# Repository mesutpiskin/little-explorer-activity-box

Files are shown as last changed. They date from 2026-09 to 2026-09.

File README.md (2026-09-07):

# Little Explorer Activity Box

[English](README.md) | [Türkçe](README.tr.md)

A no-code, no-PCB activity box that teaches cause and effect through lights,
switches, a dimmer, and sound. The enclosure is parametric, printable on a
standard 3D printer, and closed with serviceable snap fits instead of screws.

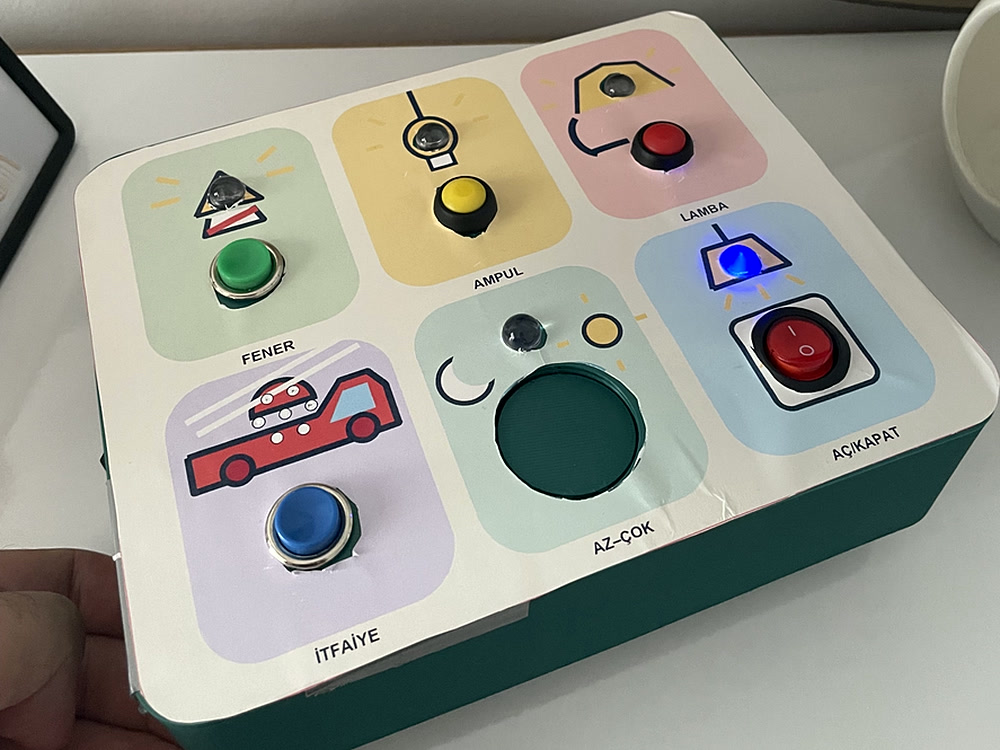
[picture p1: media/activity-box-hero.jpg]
Completed real-world activity box


> [!WARNING]
> This community hardware project is not a certified toy. A child aged 18
> months must use it only under direct adult supervision. Pull-test every
> exposed component and the back plate before each use. Remove the batteries
> immediately if anything cracks, loosens, leaks, or becomes warm.

## See it in action

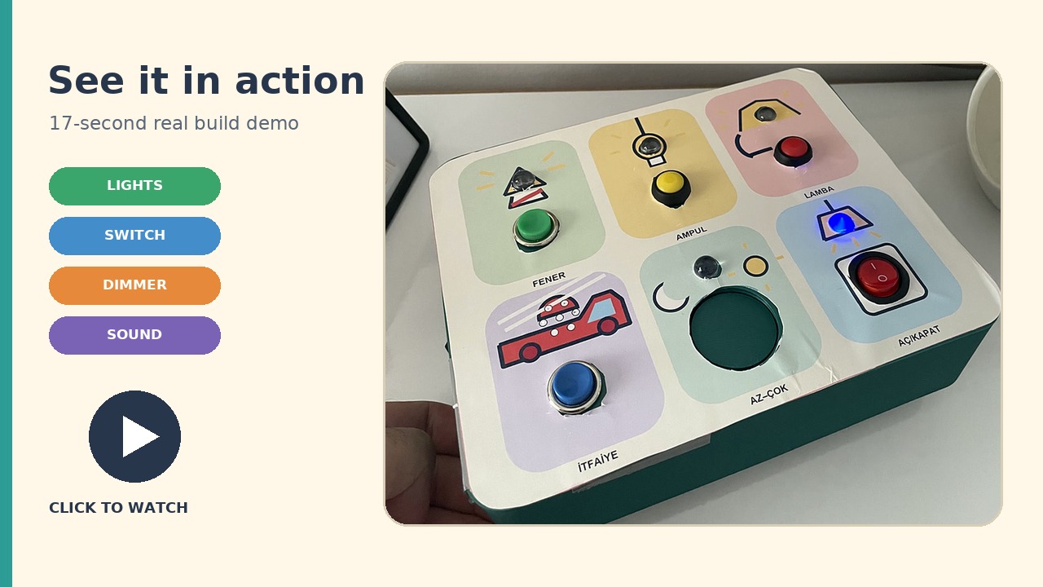
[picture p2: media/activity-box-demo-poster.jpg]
Watch the Little Explorer Activity Box demo


▶ **[Watch the 17-second real-build demo](media/activity-box-demo.mp4).** It
shows the push-button lights, maintained on/off switch, dimmer, and sound
control working on the completed box.

## What children can explore

| Activity | Input | Result |
|---|---|---|
| Lamp | Red DC184 button | Red LED lights |
| Bulb | Yellow DC184 button | Yellow LED lights |
| Beacon | Black DC180 button | Green LED lights |
| On/off | DC131A switch | Blue LED stays on or off |
| Dimmer | 1K potentiometer dial | White LED changes brightness |
| Fire engine | Blue DC180 button | Active buzzer sounds |

The six functions are simple parallel branches. No microcontroller,
breadboard, firmware, or custom PCB is required.

## Build order

### 1. Prepare the parts

Core hardware:

| Qty | Part | Purpose |
|---:|---|---|
| 2 | Semi-enclosed 2×AA battery holder | Four AA cells in series |
| 4 | AA alkaline cell | Nominal 6 V supply |
| 2 | DC184 momentary button, red and yellow | Red/yellow LED branches |
| 2 | DC180 momentary button, black and blue | Green LED and buzzer |
| 1 | DC131A 20 mm on/off switch | Blue LED branch |
| 1 | DC120 2P on/off switch | Main power |
| 1 | 1K potentiometer | White LED dimmer |
| 5 | 10 mm LED: red, yellow, green, blue, white | Light outputs |
| 5 | 330 Ω / 1 W resistor | One per LED |
| 1 | 12 mm active buzzer, 5–12 V | Sound output |
| 1 | 1 A fuse with enclosed holder | Battery short-circuit protection |
| — | Stranded wire, heat-shrink, neutral-cure silicone | Safe assembly |
| — | PETG filament | Body, back plate, and dial |

See the printable [bill of materials](docs/BOM.csv) for exact specifications.

### 2. Print the test parts first

Generate the models with:

```sh
make stl
```

Print these before the full enclosure:

- `output/stl/component-fit-test.stl` checks the purchased component sizes.
- `output/stl/snap-fit-test.stl` checks the screwless back-plate clips.

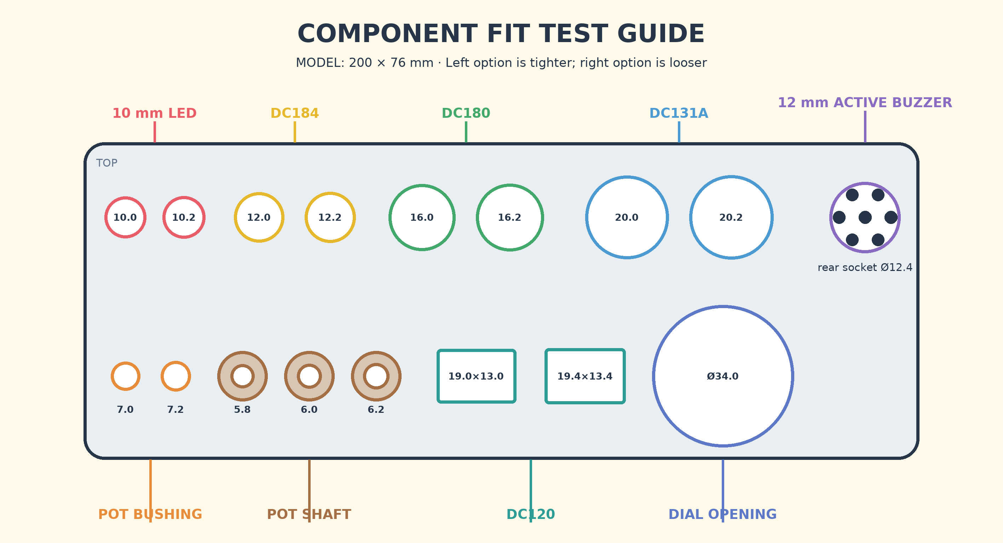
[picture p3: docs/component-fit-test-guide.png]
Component fit-test guide


The selected defaults are LED Ø10.2 mm, DC184 Ø12.0 mm, DC180 Ø16.0 mm,
DC131A Ø20.2 mm, DC120 19.0×13.0 mm, pot bushing/shaft Ø7.0/Ø6.2 mm,
and a Ø34 mm dial opening. If another fit works better, update
[`tools/project_spec.py`](tools/project_spec.py) and run `make dimensions`.

### 3. Print the enclosure

`make stl` produces:

- `activity-box-body.stl`
- `activity-box-back.stl`
- `activity-box-dial.stl`
- `snap-fit-test.stl`
- `component-fit-test.stl`

Recommended settings: PETG, 0.20 mm layers, at least four walls, five top and
bottom layers, and 25% infill. The captive dial uses a Ø36 mm × 4 mm flange
inside a Ø34 mm panel opening.

### 4. Print and apply the label

Print [the A4 label](artwork/activity-box-label-a4.pdf) at **actual size / 100%**
with “fit to page” and mirror/transfer printing disabled. The control square
must measure exactly 20 mm. Apply the label before installing components.

Editable vector source: [activity-box-label.svg](artwork/activity-box-label.svg).

### 5. Install the components

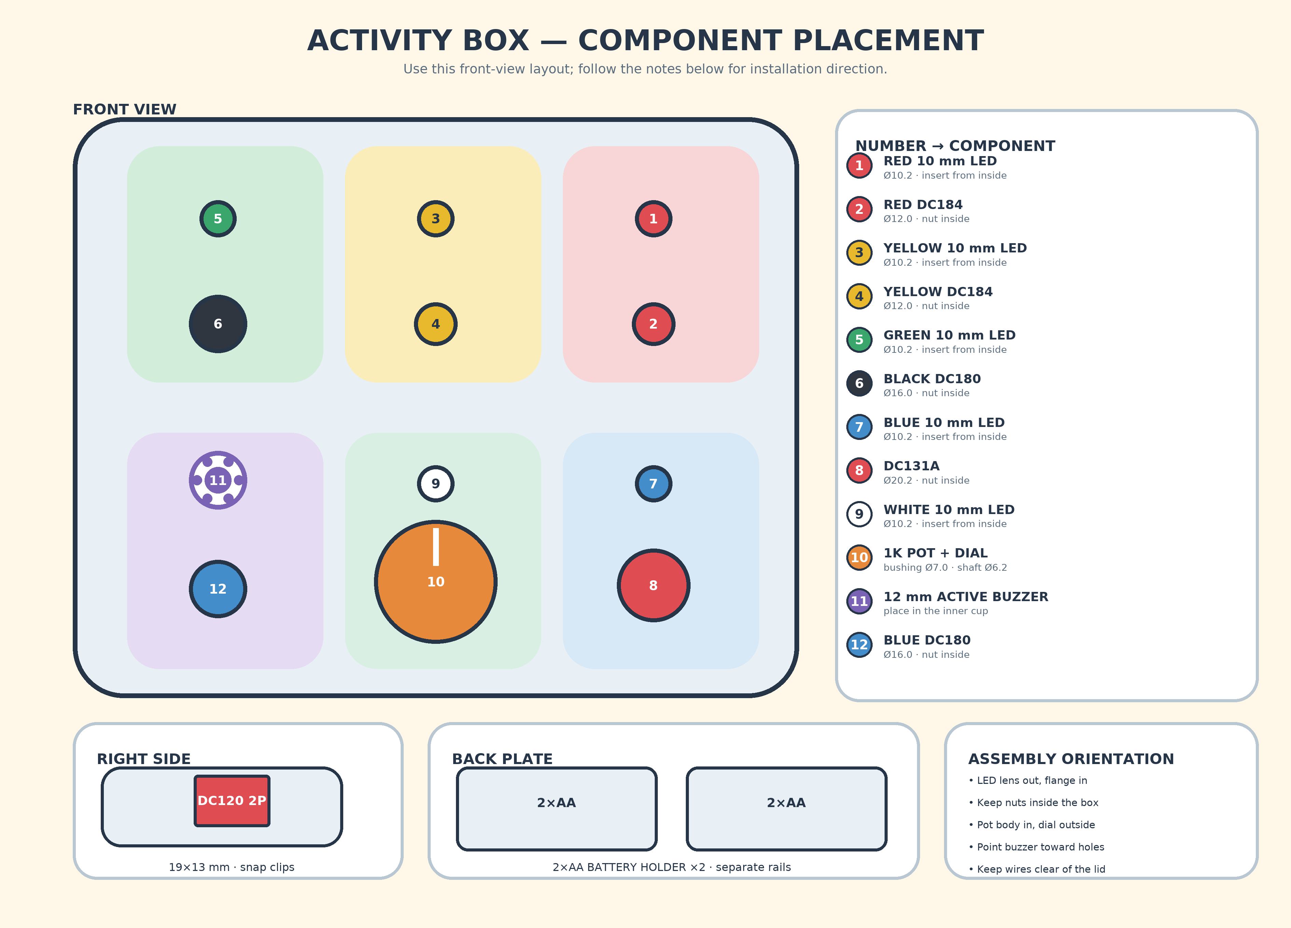
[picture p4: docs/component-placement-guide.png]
Component placement guide


Insert LEDs from inside so their wider flange remains captive. Use component
nuts or built-in clips as the primary retainers. Neutral-cure silicone may
support LEDs against vibration but must not be the only mechanical retention.
Keep the buzzer sound holes open.

The complete procedure is in the [assembly guide](docs/assembly.md).

### 6. Wire the circuit

Wiring diagram

Build the supply first, with all batteries removed:

```text
Holder A black ───────────────────────────────────── negative bus
Holder A red ─── Holder B black
Holder B red ─── 1 A fuse ─── DC120 main switch ─── positive bus
```

Then add the six branches in parallel:

```text
Positive → red DC184    → 330 Ω → red LED    → negative
Positive → yellow DC184 → 330 Ω → yellow LED → negative
Positive → black DC180  → 330 Ω → green LED  → negative
Positive → DC131A       → 330 Ω → blue LED   → negative
Positive → 1K pot       → 330 Ω → white LED  → negative
Positive → blue DC180           → active buzzer → negative
```

Use only the two switching contacts on the DC131A; leave its 12 V lamp terminal
disconnected. Identify the contacts with a multimeter instead of assuming pin
order. Join the pot wiper to the outer terminal being used.

### 7. Verify and close

1. With batteries removed, verify there is no short between the buses.
2. Confirm battery current is zero with the DC120 switched off.
3. Test one branch at a time; each LED must stay below 20 mA.
4. Route every insulated wire away from the snap clips.
5. Engage all four back-plate clips.
6. Pull-test every exposed part and the back plate before each use.

## Repository layout

| Path | Contents |
|---|---|
| [`cad/`](cad/activity_box.scad) | Parametric OpenSCAD source |
| [`artwork/`](artwork/activity-box-label.svg) | English printable label and previews |
| [`artwork/tr/`](artwork/tr/activity-box-label.svg) | Turkish printable label and previews |
| [`docs/`](docs/assembly.md) | English assembly, BOM, circuit, and placement guides |
| [`docs/tr/`](docs/tr/assembly.md) | Turkish documentation set |
| [`media/`](media/activity-box-hero.jpg) | Real-build photo, video, and video poster |
| [`assets/fonts/`](assets/fonts/LICENSE.txt) | Bundled font and its upstream license for reproducible graphics |
| [`tools/`](tools/project_spec.py) | Shared dimensions and deterministic generators |
| [`tests/`](tests/test_project_spec.py) | Geometry, output, and documentation checks |

## Rebuild and verify

Python 3 and Pillow generate the documents and artwork. OpenSCAD is required
only for STL export.

```sh
python3 -m pip install -r requirements.txt
make dimensions artwork docs
make test
make stl
make validate
```

See [CONTRIBUTING.md](CONTRIBUTING.md) before proposing changes.

## License

Hardware design, CAD, artwork, and documentation are licensed under
[CERN-OHL-P-2.0](LICENSE). Build scripts and tests are licensed under the
[MIT License](LICENSES/MIT.txt). See [license scope](LICENSES/README.md).

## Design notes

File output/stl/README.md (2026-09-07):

# STL export

[English](README.md) | [Türkçe](README.tr.md)

Generated STL files are intentionally not committed. Install OpenSCAD, then
run the following commands from the repository root:

```sh
make stl
make validate
```

The export creates:

- `activity-box-body.stl`
- `activity-box-back.stl`
- `activity-box-dial.stl`
- `snap-fit-test.stl`
- `component-fit-test.stl`

Print and verify the two test models before printing the enclosure.

## Print orientation

- Body: print with the front face down on the build plate.
- Back plate: print with the outer face down on the build plate.
- Dial: print with the flange down on the build plate.

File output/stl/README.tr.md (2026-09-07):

# STL dışa aktarma

[English](README.md) | [Türkçe](README.tr.md)

Üretilmiş STL dosyaları repoya eklenmez. OpenSCAD'i kurduktan sonra proje
kökünde şu komutları çalıştırın:

```sh
make stl
make validate
```

Oluşturulan dosyalar:

- `activity-box-body.stl`
- `activity-box-back.stl`
- `activity-box-dial.stl`
- `snap-fit-test.stl`
- `component-fit-test.stl`

Ana kutudan önce iki test modelini basıp doğrulayın.

## Baskı yönü

- Gövde: ön yüzü tablaya gelecek şekilde basın.
- Arka kapak: dış yüzü tablaya gelecek şekilde basın.
- Çark: flanşı tablaya gelecek şekilde basın.

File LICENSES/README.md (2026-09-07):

# License scope

[English](README.md) | [Türkçe](README.tr.md)

This repository uses two permissive licenses so that hardware design files and
software tooling receive terms appropriate to their use.

## CERN-OHL-P-2.0

The [CERN Open Hardware Licence Version 2 — Permissive](../LICENSE) applies to:

- `cad/`
- `artwork/`
- `docs/`
- `media/`
- `output/`
- `assets/`, except the third-party `assets/fonts/` directory covered below
- `README.md` and `README.tr.md`
- `CONTRIBUTING.md` and `CONTRIBUTING.tr.md`

SPDX identifier: `CERN-OHL-P-2.0`

## MIT

The [MIT License](MIT.txt) applies to:

- `tools/`
- `tests/`
- `Makefile`
- automation and configuration files

SPDX identifier: `MIT`

## Third-party fonts

The DejaVu Sans font files in `assets/fonts/` retain their upstream license.
See [`assets/fonts/LICENSE.txt`](../assets/fonts/LICENSE.txt).

Unless a file states otherwise, contributions are accepted under the license
assigned to that path above.

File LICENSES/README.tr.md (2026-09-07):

# Lisans kapsamı

[English](README.md) | [Türkçe](README.tr.md)

Bu repo, donanım tasarım dosyaları ile yazılım araçlarının kullanımına uygun
koşullar sağlamak için iki izin verici lisans kullanır.

## CERN-OHL-P-2.0

[CERN Açık Donanım Lisansı Sürüm 2 — Permissive](../LICENSE) şu yollar için
geçerlidir:

- `cad/`
- `artwork/`
- `docs/`
- `media/`
- `output/`
- Aşağıda belirtilen üçüncü taraf `assets/fonts/` dizini hariç `assets/`
- `README.md` ve `README.tr.md`
- `CONTRIBUTING.md` ve `CONTRIBUTING.tr.md`

SPDX kimliği: `CERN-OHL-P-2.0`

## MIT

[MIT Lisansı](MIT.txt) şu yollar için geçerlidir:

- `tools/`
- `tests/`
- `Makefile`
- otomasyon ve yapılandırma dosyaları

SPDX kimliği: `MIT`

## Üçüncü taraf fontlar

`assets/fonts/` altındaki DejaVu Sans dosyaları kendi kaynak lisanslarını
korur. Bkz. [`assets/fonts/LICENSE.txt`](../assets/fonts/LICENSE.txt).

Bir dosyada aksi belirtilmedikçe katkılar yukarıda o dosya yoluna atanan
lisans altında kabul edilir.

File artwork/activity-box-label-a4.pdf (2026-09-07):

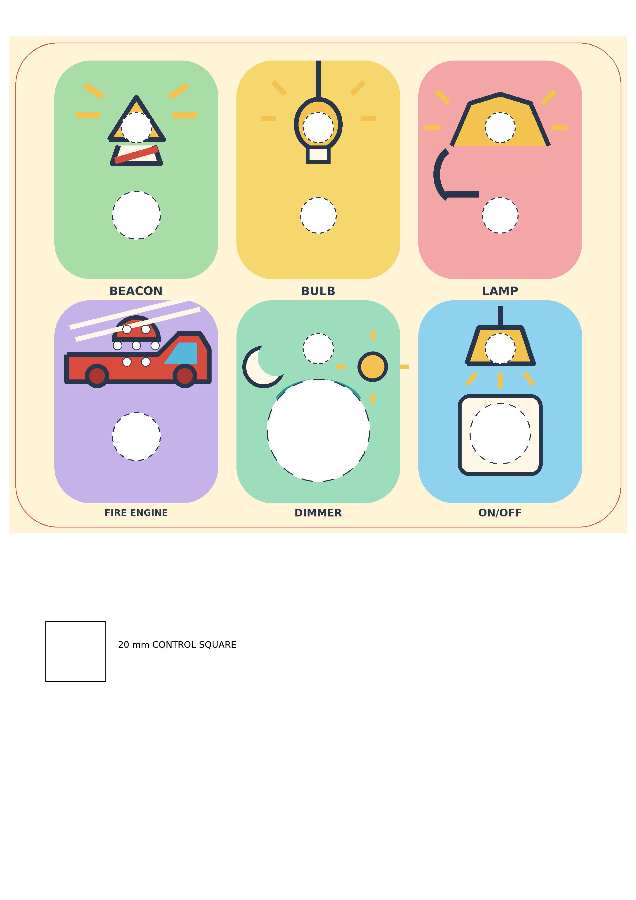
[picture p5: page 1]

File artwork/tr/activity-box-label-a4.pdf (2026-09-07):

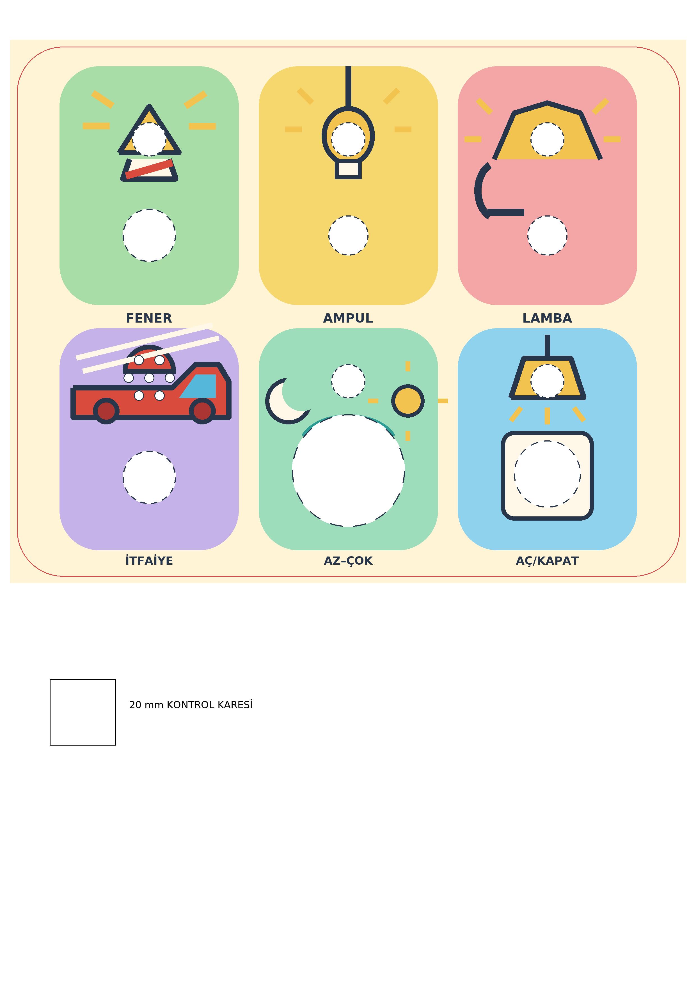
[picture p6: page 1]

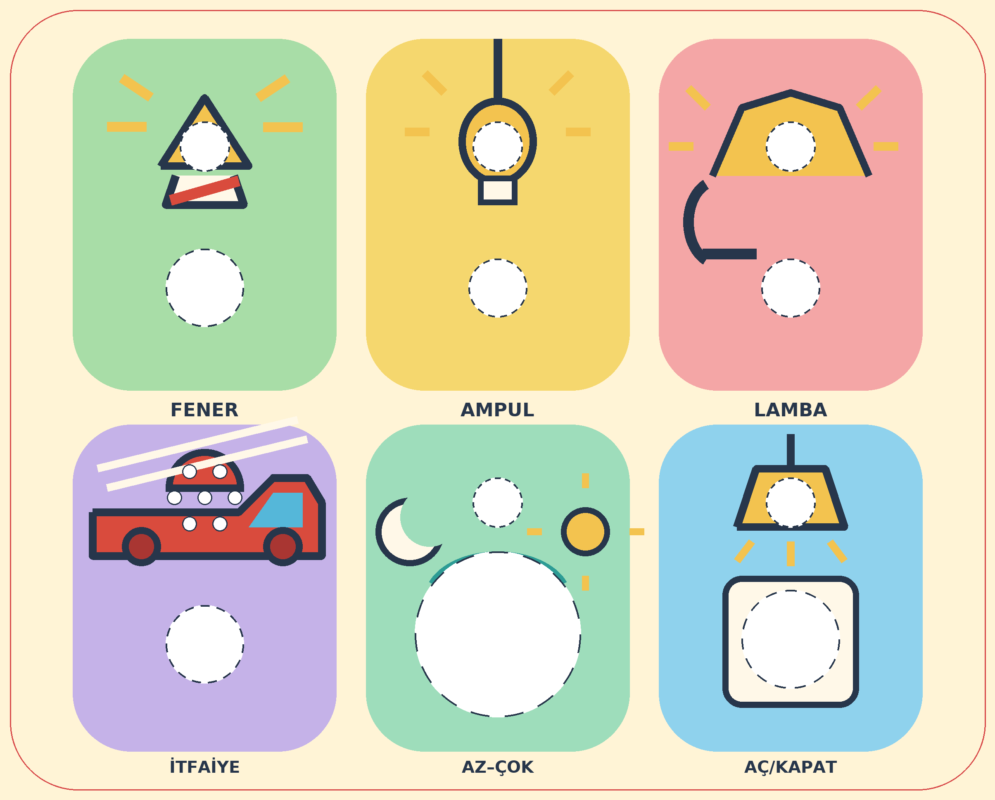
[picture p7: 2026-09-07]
artwork/tr/activity-box-label-preview.png

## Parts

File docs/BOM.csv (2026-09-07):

quantity | part | specification | use
1 | 1 A fuse | Enclosed holder or inline type | As close as possible to Holder B positive
2 | 2×AA semi-enclosed battery holder | Approx. 58×32×15 mm | Series connection for 4×AA
4 | AA alkaline battery | 1.5 V; matching brand and state of charge | 6 V nominal supply
2 | DC184 momentary push button | Red and yellow; Ø12.0 mm tested hole | Red and yellow LED branches
2 | DC180 momentary push button | Black and blue; Ø16.0 mm tested hole | Green LED and buzzer
1 | DC131A on/off switch | Ø20.2 mm; 12 V illuminated type | Use switch contacts only
1 | DC120 2P on/off switch | 19.0×13.0 mm tested cutout | Main power
1 | 1K potentiometer | 7.0 mm bushing; 6.2 mm shaft socket | White LED dimmer
10 | 330 ohm 1 W resistor | Orange-orange-brown | 5 used plus spares
4 | 10 mm LED | Red, yellow, green, blue | One 330 Ω resistor per LED
1 | 10 mm white LED | Clear, standard two-lead | Dimmer branch
1 | 12 mm active buzzer | 5–12 V, self-driven | Do not use the passive 22 mm buzzer
2 m | stranded wire | 0.22–0.50 mm² | Red and black recommended
1 set | heat-shrink tubing | 2–4 mm | Insulate every solder joint
1 tube | neutral-cure silicone | Electronics-safe | LED vibration support; not the sole retainer
print | approximately 450 g | 1.75 mm PETG filament | Body, back plate, and dial

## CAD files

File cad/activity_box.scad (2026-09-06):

include <generated_dimensions.scad>

$fn = 48;
part = is_undef(part) ? "assembly" : part;
dial_grip_d = 32;
dial_flange_d = 36;
dial_flange_t = 4;
buzzer_port_depth = front_t + 1.4;
eps = 0.15;

module rounded_rect_2d(w, h, r) {
    hull() {
        for (x = [r, w - r], y = [r, h - r])
            translate([x, y]) circle(r = r);
    }
}

module rounded_box(w, h, d, r) {
    linear_extrude(height = d) rounded_rect_2d(w, h, r);
}

function front_xy(position) = [position[0], box_h - position[1]];

module circular_panel_hole(position, diameter) {
    xy = front_xy(position);
    translate([xy[0], xy[1], -eps])
        cylinder(h = front_t + 2 * eps, d = diameter);
}

module rectangular_panel_hole(position, size) {
    xy = front_xy(position);
    translate([xy[0] - size[0] / 2, xy[1] - size[1] / 2, -eps])
        cube([size[0], size[1], front_t + 2 * eps]);
}

module buzzer_holes_at(xy) {
    for (angle = [0 : 60 : 300])
        translate([xy[0] + 6.2 * cos(angle), xy[1] + 6.2 * sin(angle), -eps])
            cylinder(h = buzzer_port_depth + 2 * eps, d = 3);
    translate([xy[0], xy[1], -eps])
        cylinder(h = buzzer_port_depth + 2 * eps, d = 3);
}

module buzzer_holes() {
    buzzer_holes_at(front_xy(pos_buzzer));
}

module panel_cutouts() {
    for (position = [pos_red_led, pos_yellow_led, pos_green_led,
                     pos_switch_led, pos_dimmer_led])
        circular_panel_hole(position, led_hole_d);
    for (position = [pos_red_button, pos_yellow_button])
        circular_panel_hole(position, dc184_button_hole_d);
    for (position = [pos_green_button, pos_buzzer_button])
        circular_panel_hole(position, dc180_button_hole_d);
    circular_panel_hole(pos_rocker, room_switch_hole_d);
    circular_panel_hole(pos_dial, dial_opening_d);
    buzzer_holes();
}

module open_led_guard(position) {
    xy = front_xy(position);
    translate([xy[0], xy[1], front_t - eps])
        difference() {
            cylinder(h = 6, d = 16);
            translate([0, 0, -eps]) cylinder(h = 6 + 2 * eps, d = 12.4);
        }
}

module buzzer_cup_at(xy) {
    translate([xy[0], xy[1], front_t - eps])
        difference() {
            cylinder(h = 8, d = 17);
            translate([0, 0, 1]) cylinder(h = 7.2, d = 12.4);
        }
}

module buzzer_cup() {
    buzzer_cup_at(front_xy(pos_buzzer));
}

module pot_mount_bridge() {
    xy = front_xy(pos_dial);
    bridge_z = front_t + 13;
    union() {
        for (x = [xy[0] - 28, xy[0] + 24])
            translate([x, xy[1] - 6, front_t - eps])
                cube([4, 12, bridge_z - front_t + eps]);
        difference() {
            translate([xy[0] - 28, xy[1] - 6, bridge_z])
                cube([56, 12, 2.8]);
            translate([xy[0], xy[1], bridge_z - eps])
                cylinder(h = 2.8 + 2 * eps, d = pot_bushing_hole_d);
        }
    }
}

module wire_clip(x, y) {
    translate([x, y, front_t - eps])
        difference() {
            cube([12, 6, 5]);
            translate([2, -eps, 1.8]) cube([8, 6 + 2 * eps, 3.5]);
        }
}

module back_stop_ring() {
    translate([0, 0, box_d - back_t - 1.2])
        linear_extrude(height = 1.2)
            difference() {
                offset(delta = -wall) rounded_rect_2d(box_w, box_h, corner_r);
                offset(delta = -(wall + 1.4)) rounded_rect_2d(box_w, box_h, corner_r);
            }
}

module master_switch_cutout() {
    translate([box_w - wall - eps, box_h / 2 - master_switch_size[0] / 2,
               box_d / 2 - master_switch_size[1] / 2])
        cube([wall + 2 * eps, master_switch_size[0], master_switch_size[1]]);
}

module service_holes() {
    service_z = box_d - back_t - 6.5;
    translate([-eps, box_h / 2, service_z])
        rotate([0, 90, 0]) cylinder(h = wall + 2 * eps, d = 3);
    translate([box_w - wall - eps, box_h / 2, service_z])
        rotate([0, 90, 0]) cylinder(h = wall + 2 * eps, d = 3);
}

module body() {
    difference() {
        union() {
            difference() {
                rounded_box(box_w, box_h, box_d, corner_r);
                translate([wall, wall, front_t])
                    rounded_box(box_w - 2 * wall, box_h - 2 * wall,
                                box_d - front_t + eps, corner_r - wall);
            }
            for (position = [pos_red_led, pos_yellow_led, pos_green_led,
                             pos_switch_led, pos_dimmer_led])
                open_led_guard(position);
            buzzer_cup();
            pot_mount_bridge();
            wire_clip(63, 77);
            wire_clip(126, 77);
            back_stop_ring();
        }
        panel_cutouts();
        master_switch_cutout();
        service_holes();
    }
}

module back_plate() {
    plate_x = wall + fit_clearance;
    plate_y = wall + fit_clearance;
    translate([plate_x, plate_y, 0])
        linear_extrude(height = back_t)
            rounded_rect_2d(box_w - 2 * plate_x, box_h - 2 * plate_y,
                            corner_r - plate_x);
}

module tongue_ring() {
    inset = wall + fit_clearance + 0.7;
    translate([0, 0, back_t - eps])
        linear_extrude(height = 4.5)
            difference() {
                offset(delta = -inset) rounded_rect_2d(box_w, box_h, corner_r);
                offset(delta = -(inset + 1.2)) rounded_rect_2d(box_w, box_h, corner_r);
            }
}

module side_lock(left = true) {
    tab_x = left ? wall + fit_clearance
                 : box_w - wall - fit_clearance - 1.2;
    hook_x = left ? tab_x - 0.7 : tab_x + 1.2;
    translate([tab_x, box_h / 2 - 7, back_t - eps]) cube([1.2, 14, 8]);
    translate([hook_x, box_h / 2 - 7, back_t + 6.2]) cube([0.7, 14, 1.2]);
}

module passive_lock(top = true) {
    tab_y = top ? box_h - wall - fit_clearance - 1.2
                : wall + fit_clearance;
    hook_y = top ? tab_y + 1.2 : tab_y - 0.7;
    translate([box_w / 2 - 7, tab_y, back_t - eps]) cube([14, 1.2, 6]);
    translate([box_w / 2 - 7, hook_y, back_t + 4.5]) cube([14, 0.7, 1.1]);
}

module battery_rails() {
    bay_w = battery_bay_size[0] + 1;
    bay_h = battery_bay_size[1] + 1;
    x0 = battery_bay_pos[0];
    y0 = battery_bay_pos[1];
    rail_h = 5;
    for (x = [x0, x0 + bay_w - 2.2])
        translate([x, y0, back_t - eps]) cube([2.2, bay_h, rail_h]);
    for (y = [y0, y0 + bay_h - 2.2])
        translate([x0, y, back_t - eps]) cube([bay_w, 2.2, rail_h]);
}

module battery_center_divider() {
    bay_w = battery_bay_size[0] + 1;
    bay_h = battery_bay_size[1] + 1;
    x0 = battery_bay_pos[0];
    y0 = battery_bay_pos[1];
    translate([x0 + bay_w / 2 - 1.1, y0, back_t - eps])
        cube([2.2, bay_h, 5]);
}

module back() {
    union() {
        back_plate();
        tongue_ring();
        side_lock(true);
        side_lock(false);
        passive_lock(true);
        passive_lock(false);
        battery_rails();
        battery_center_divider();
    }
}

module dial() {
    difference() {
        union() {
            cylinder(h = dial_flange_t, d = dial_flange_d);
            translate([0, 0, dial_flange_t - 0.1])
                cylinder(h = 8, d = dial_grip_d);
            for (angle = [0 : 30 : 330])
                rotate([0, 0, angle])
                    translate([dial_grip_d / 2 - 1, 0, dial_flange_t + 0.2])
                    cube([1.2, 1.8, 7]);
        }
        translate([0, 0, -eps]) cylinder(h = 8, d = pot_shaft_d);
    }
}

module snap_fit_test() {
    // Receiving wall with a 3 mm service passage.
    difference() {
        cube([18, 24, 12]);
        translate([3, 3, 2]) cube([15.2, 18, 10.2]);
        translate([-eps, 12, 7]) rotate([0, 90, 0]) cylinder(h = 3.3, d = 3);
    }
    // Separate coupon tab, printed beside the receiving wall.
    translate([24, 4, 0]) {
        cube([12, 16, back_t]);
        translate([0.55, 1, back_t - eps]) cube([1.2, 14, 8]);
        translate([-0.2, 1, back_t + 6.2]) cube([0.75, 14, 1.2]);
    }
}

module component_fit_test() {
    test_w = fit_size[0];
    test_h = fit_size[1];
    test_r = fit_corner_radius;
    led_fit_diameters = fit_led_diameters;
    dc184_fit_diameters = fit_dc184_diameters;
    dc180_fit_diameters = fit_dc180_diameters;
    dc131a_fit_diameters = fit_dc131a_diameters;
    pot_bushing_fit_diameters = fit_pot_bushing_diameters;
    shaft_fit_diameters = fit_shaft_diameters;
    dc120_fit_sizes = fit_dc120_sizes;
    top_y = fit_top_y;
    bottom_y = fit_bottom_y;
    led_x = fit_led_x;
    dc184_x = fit_dc184_x;
    dc180_x = fit_dc180_x;
    dc131a_x = fit_dc131a_x;
    pot_bushing_x = fit_pot_bushing_x;
    shaft_x = fit_shaft_x;
    dc120_x = fit_dc120_x;
    dial_xy = fit_dial_xy;
    buzzer_xy = fit_buzzer_xy;
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

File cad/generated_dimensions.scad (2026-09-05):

// Generated by tools/generate_dimensions.py; do not edit by hand.
box_w = 200;
box_h = 160;
box_d = 52;
corner_r = 14;
wall = 2.6;
front_t = 3.2;
back_t = 2.8;
fit_clearance = 0.25;
led_hole_d = 10.2;
dc184_button_hole_d = 12.0;
dc180_button_hole_d = 16.0;
room_switch_hole_d = 20.2;
dial_opening_d = 34.0;
pot_bushing_hole_d = 7.0;
pot_shaft_d = 6.2;
master_switch_size = [19.0, 13.0];
battery_bay_size = [62, 68, 18];
battery_bay_pos = [69, 46];
fit_size = [200, 76];
fit_corner_radius = 5;
fit_top_y = 58;
fit_bottom_y = 20;
fit_led_diameters = [10.0, 10.2];
fit_dc184_diameters = [12.0, 12.2];
fit_dc180_diameters = [16.0, 16.2];
fit_dc131a_diameters = [20.0, 20.2];
fit_pot_bushing_diameters = [7.0, 7.2];
fit_shaft_diameters = [5.8, 6.0, 6.2];
fit_dc120_sizes = [[19.0, 13.0], [19.4, 13.4]];
fit_led_x = [10, 24];
fit_dc184_x = [42, 59];
fit_dc180_x = [81, 102];
fit_dc131a_x = [130, 155];
fit_pot_bushing_x = [10, 22];
fit_shaft_x = [38, 54, 70];
fit_dc120_x = [94, 120];
fit_dial_xy = [153, 20];
fit_buzzer_xy = [187, 58];
pos_red_led = [40, 28];
pos_red_button = [40, 57];
pos_yellow_led = [100, 28];
pos_yellow_button = [100, 57];
pos_green_led = [160, 28];
pos_green_button = [160, 57];
pos_switch_led = [40, 101];
pos_rocker = [40, 129];
pos_dimmer_led = [100, 101];
pos_dial = [100, 128];
pos_buzzer = [160, 100];
pos_buzzer_button = [160, 130];

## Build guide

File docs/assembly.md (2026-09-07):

# Assembly and verification guide

## Important safety notice

This community hardware project is not a certified toy. A child aged 18
months must use it only under direct adult supervision. Remove the batteries
immediately if any part cracks, loosens, or becomes warm. Do not use lithium
batteries. A screwless enclosure still requires regular pull testing of the
back plate and every exposed component.

## 1. Verified fit dimensions

The component coupon confirmed 10.2 mm for 10 mm LEDs, 12.0 mm for DC184,
16.0 mm for DC180, and 20.2 mm for DC131A. The selected potentiometer sizes
are a 7.0 mm bushing hole and a 6.2 mm shaft socket. The DC120 cutout is
19.0×13.0 mm. The buzzer cup was tested and the dial opening remains 34 mm.
Print the coupon again whenever the printer, filament, or component batch
changes, then update `tools/project_spec.py` if needed.

## 2. Print the component coupon first

With `component-fit-test.stl` horizontal, read the openings from left to right:

Component fit-test guide

- Top row: LED 10.0 / 10.2; DC184 12.0 / 12.2; DC180 16.0 / 16.2;
  DC131A 20.0 / 20.2; 12 mm buzzer cup at the far right.
- Bottom row: pot bushing 7.0 / 7.2; shaft socket 5.8 / 6.0 / 6.2;
  DC120 19.0×13.0 / 19.4×13.4; 34 mm dial opening.

The part should enter without force while its nut or clips seat fully. It must
not pull out by hand. Transfer the best dimension to `tools/project_spec.py`
before regenerating the body. The shared bay for two 2×AA holders measures
62×68×18 mm and must also be checked against the purchased parts.

Print `snap-fit-test.stl` next. The tab should engage easily but resist opening
with one hand. Increase `clearance` by 0.10 mm if too tight or reduce it by
0.10 mm if loose. Recommended print settings: PETG, 0.20 mm layers, at least
four walls, five top/bottom layers, and 25% infill. Reject parts with sharp
burrs, layer separation, or cracked clips.

## 3. Apply the label

Print `artwork/activity-box-label-a4.pdf` at **actual size / 100%** with
“fit to page” disabled. Verify that the control square measures exactly 20 mm.
For ordinary white adhesive paper, keep mirror/transfer printing disabled; the
printed face points outward. Cut on the red trim line and have an adult remove
the component openings. Degrease the panel, align the label to the holes, and
apply it from the center outward.

## 4. Install front-panel components

Component placement guide

Insert each 10 mm LED from inside the enclosure. The lens passes through the
10.2 mm hole while the wider flange remains inside as the mechanical retainer.
Apply a small amount of neutral-cure silicone around the printed guard for
vibration support only. Keep silicone away from the lens. The long lead is
positive; the short lead or flat edge is negative.

Secure the red and yellow DC184 buttons and the black and blue DC180 buttons
with their nuts. Fit the DC131A in the 20.2 mm opening. Insert the dial from
inside the 34 mm opening; its 36 mm diameter, 4 mm thick flange remains captive
and clears the LED guard. Fasten the 1K pot to the printed bridge, using the
shaft socket selected with the coupon. Place the buzzer in its cup with its
opening toward the sound holes and retain it only around the edge.

## 5. Wire the battery holders and main power

With all batteries removed, connect the holders in series:

1. Holder A black wire → system negative bus.
2. Holder A red wire → Holder B black wire; solder and fully cover the joint
   with heat-shrink tubing.
3. Holder B red wire → 1 A fuse → DC120 2P main switch → system positive bus.

This produces four AA cells in series: 6 V nominal and approximately 6.4 V
with fresh alkaline cells. Use matching cells of the same brand, chemistry,
and state of charge in both holders.

## 6. Wire the six parallel branches

1. Positive → red DC184 → 330 ohm 1 W → red LED long lead; short lead → negative.
2. Positive → yellow DC184 → 330 ohm 1 W → yellow LED → negative.
3. Positive → black DC180 → 330 ohm 1 W → green LED → negative.
4. Positive → DC131A switch contacts → 330 ohm 1 W → blue LED → negative.
   Leave the DC131A 12 V lamp terminal disconnected. Do not assume pin order;
   identify the two switch contacts with a multimeter in continuity mode.
5. Positive → joined pot wiper and one outer terminal → 330 ohm 1 W → white
   LED → negative. Leave the other outer pot terminal disconnected.
6. Positive → blue DC180 → active buzzer positive; buzzer negative → negative.

Resistors have no polarity, and every LED requires its own 330 ohm resistor.
The 1 W resistor is electrically suitable but physically larger than a 0.25 W
part. Do not leave breadboards or loose jumper wires in the finished product.
Use stranded wire, solder every joint, and cover all exposed conductors with
heat-shrink tubing.

## 7. Electrical verification

With batteries removed, use a multimeter to verify there is no short between
the positive and negative buses. Battery current must be zero when DC120 is
off. With fresh cells, theoretical maximum LED currents are approximately
13.3 mA red, 13.0 mA yellow, and 10.3 mA green/blue/white. Test one branch at a
time and confirm each measured LED current stays below 20 mA. Sound the buzzer
for only a few seconds; if it is too loud, place thin felt in front without
blocking every sound hole.

## 8. Close and inspect the enclosure

Place the two battery holders in their separate rear rails and keep wires away
from all clips. Press the back plate tongue squarely into the body groove until
all four clips engage. The back must not open by hand unless both opposing
service latches are pressed at the same time with two thin tools. Pull-test
every button, LED, switch, and the dial before each use. Do not give the box to
the child if any part moves, cracks, or loosens.

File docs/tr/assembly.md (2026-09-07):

# Montaj ve kontrol kılavuzu

## Önemli güvenlik notu

Bu topluluk donanım projesi sertifikalı bir oyuncak değildir. 18 aylık çocuk
yalnızca bir yetişkinin doğrudan gözetiminde kullanmalıdır. Kırılan, çatlayan,
gevşeyen veya ısınan bir parça görülürse pilleri hemen çıkarın. Lityum pil
kullanmayın. Vida kullanılmaması, kapağın ve dış parçaların düzenli çekme
kontrolü gereğini ortadan kaldırmaz.

## 1. Doğrulanan geçme ölçüleri

Komponent kuponunda 10 mm LED için 10,2 mm, DC184 için 12,0 mm, DC180 için
16,0 mm ve DC131A için 20,2 mm doğrulandı. Pot burcu 7,0 mm, pot mili 6,2 mm,
DC120 kesiti 19,0×13,0 mm'dir. Buzzer kabı test edildi; çark açıklığı 34 mm'dir.
Yazıcı, filament veya komponent partisi değişirse tam gövdeden önce kuponu
yeniden basın ve gerekirse `tools/project_spec.py` değerlerini düzeltin.

## 2. Önce komponent test kuponunu basın

`component-fit-test.stl` yatay tutulduğunda delikler soldan sağa şöyledir:

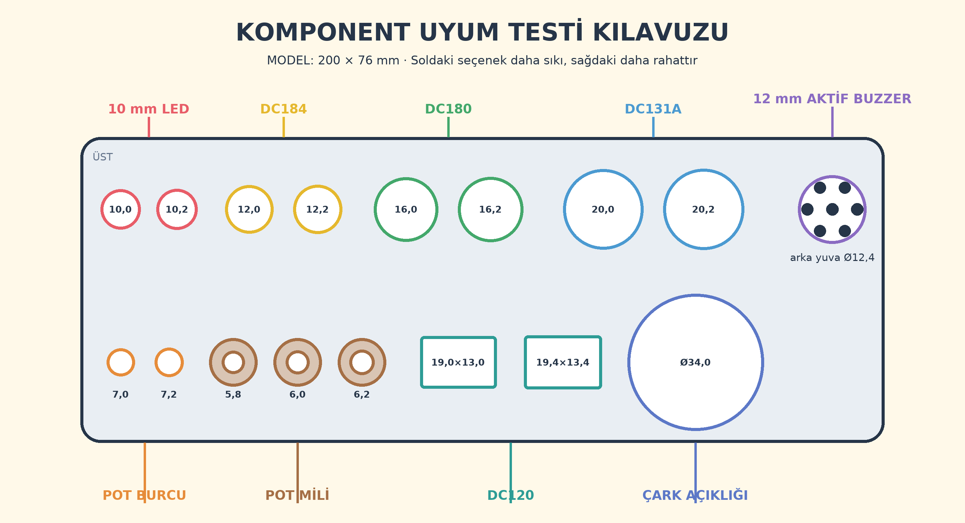
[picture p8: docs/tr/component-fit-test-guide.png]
Komponent test plakası kılavuzu


- Üst sıra: LED 10,0 / 10,2; DC184 12,0 / 12,2; DC180 16,0 / 16,2;
  DC131A 20,0 / 20,2; en sağda 12 mm buzzer kabı.
- Alt sıra: pot burcu 7,0 / 7,2; mil yuvası 5,8 / 6,0 / 6,2;
  DC120 19,0×13,0 / 19,4×13,4; 34 mm çark açıklığı.

Parça zorlamadan girmeli, somun veya tırnak bütün yüzeye oturmalı ve elle
çekildiğinde çıkmamalıdır. En iyi ölçüyü `tools/project_spec.py` içine aktarıp
ana modeli yeniden üretin. İki 2×AA pil yuvasının ortak bölmesi 62×68×18 mm'dir;
bu ölçüyü de satın alınan parçalarla doğrulayın.

Ardından `snap-fit-test.stl` tolerans numunesini basın. Tırnak rahat girip tek
elle çıkmamalıdır. Çok sıkıysa `clearance` değerini 0,10 mm artırın; gevşekse
0,10 mm azaltın. Önerilen ayarlar: PETG, 0,20 mm katman, en az dört çevre, beş
alt/üst katman ve yüzde 25 dolgu. Katman ayrılması, sivri çapak veya tırnak
çatlağı olan parçayı kullanmayın.

## 3. Etiketi uygulayın

`artwork/tr/activity-box-label-a4.pdf` dosyasını **gerçek boyut / yüzde 100**
seçeneğiyle, sayfaya sığdırmayı kapatarak basın. Kontrol karesinin tam 20 mm
olduğunu ölçün. Normal beyaz yapışkanlı kâğıtta ayna/transfer seçeneği kapalı
olmalı; baskılı yüz dışa bakmalıdır. Kırmızı kesim çizgisinden kesin ve
komponent boşluklarını yalnızca bir yetişkin çıkarsın. Yüzeyi yağdan arındırın,
etiketi deliklere hizalayın ve ortadan kenarlara doğru yapıştırın.

## 4. Ön panel bileşenlerini takın

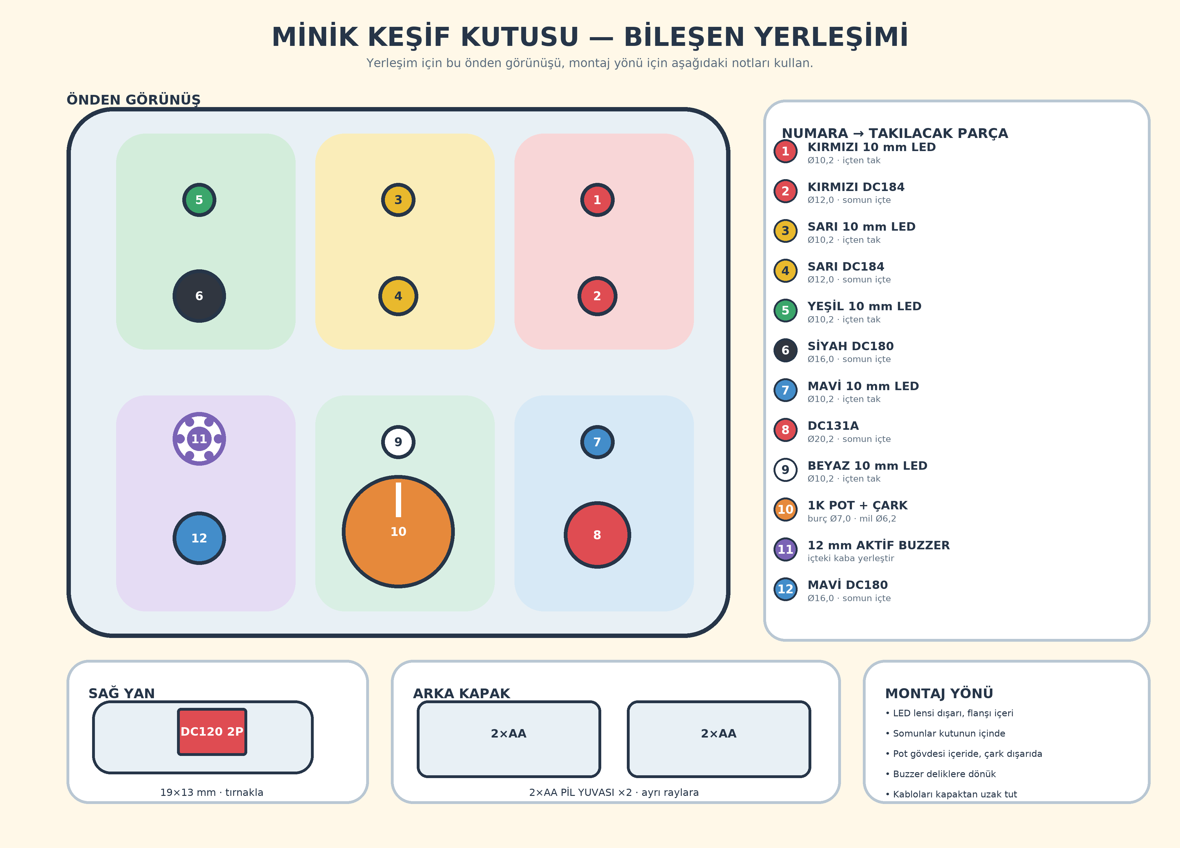
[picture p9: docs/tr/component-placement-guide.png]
Bileşen yerleşim şeması


10 mm LED'leri kutunun içinden dışarı doğru yerleştirin. Lens 10,2 mm delikten
çıkar; geniş LED flanşı içeride mekanik tutucu olarak kalır. Baskı koruma
halkasına yalnız titreşim desteği için az miktarda nötr kürlenen silikon sürün.
Lense silikon sürmeyin. Uzun bacak artı, kısa bacak veya düz kenar eksidir.

Kırmızı ve sarı DC184'leri, siyah ve mavi DC180'leri somunlarıyla sabitleyin.
DC131A'yı 20,2 mm deliğe takın. Çarkı 34 mm açıklığa içeriden yerleştirin;
Ø36 mm ve 4 mm kalınlığındaki flanşı içeride hapsolur ve LED yuvasına çarpmaz.
1K potu baskı köprüsüne somunlayın ve kuponda seçilen mil yuvasını kullanın.
Buzzer'ı açık yüzü ses deliklerine bakacak şekilde kaba yerleştirip yalnızca
kenarından sabitleyin.

## 5. Pil yuvalarını ve ana gücü bağlayın

Piller takılı değilken iki pil yuvasını seri bağlayın:

1. Yuva A siyah kablo → sistem eksi dağıtım hattı.
2. Yuva A kırmızı kablo → Yuva B siyah kablo; ek yerini lehimleyip makaronla
   tamamen kapatın.
3. Yuva B kırmızı kablo → 1 A sigorta → DC120 2P ana güç anahtarı → sistem
   artı dağıtım hattı.

Bu bağlantı dört AA pili seri yapar: nominal 6 V, taze alkalin pillerle yaklaşık
6,4 V. İki yuvada da aynı marka, tip ve dolulukta pil kullanın.

## 6. Altı paralel kolu bağlayın

1. Artı → kırmızı DC184 → 330 ohm 1 W → kırmızı LED uzun bacak; kısa bacak → eksi.
2. Artı → sarı DC184 → 330 ohm 1 W → sarı LED → eksi.
3. Artı → siyah DC180 → 330 ohm 1 W → yeşil LED → eksi.
4. Artı → DC131A anahtar kontakları → 330 ohm 1 W → mavi LED → eksi.
   DC131A'nın 12 V lamba ucunu bağlamayın. Pin dizilimini varsaymayın;
   kullanılacak iki kontağı multimetrenin süreklilik moduyla bulun.
5. Artı → birbirine bağlanan pot orta ucu ve bir dış uç → 330 ohm 1 W → beyaz
   LED → eksi. Potun diğer dış ucunu boş bırakın.
6. Artı → mavi DC180 → aktif buzzer artı; buzzer eksi → eksi.

Dirençlerin yönü yoktur; her LED kendi 330 ohm direncini kullanır. 1 W direnç
elektriksel olarak uygundur, yalnızca 0,25 W tipten daha büyüktür. Kalıcı
oyuncakta breadboard veya gevşek jumper bırakmayın. Çok telli kablo kullanın,
tüm ekleri lehimleyin ve açık iletkenleri makaronla kapatın.

## 7. Elektrik kontrolünü yapın

Piller yokken artı ve eksi arasında kısa devre olmadığını multimetreyle
doğrulayın. DC120 kapalıyken pil akımı sıfır olmalıdır. Taze pillerle teorik en
yüksek LED akımı kırmızıda yaklaşık 13,3 mA, sarıda 13,0 mA, yeşil/mavi/beyazda
10,3 mA'dır. Her kolu ayrı çalıştırın ve ölçülen akımın 20 mA altında kaldığını
doğrulayın. Buzzer'ı yalnızca birkaç saniye deneyin; fazla yüksekse ses
deliklerini tamamen kapatmadan önüne ince keçe yerleştirin.

## 8. Kutuyu kapatın ve denetleyin

İki pil yuvasını arka kapaktaki ayrı raylara yerleştirin; kablolar tırnaklardan
uzak kalsın. Kapağın dilini gövdenin yivine düz bastırıp dört tırnağı oturtun.
Karşılıklı iki servis mandalı aynı anda iki ince aletle bastırılmadan kapak elle
açılmamalıdır. Her kullanımdan önce her buton, LED, anahtar ve çarkı çekerek
kontrol edin. Bir parça hareket ediyor, çatlıyor veya gevşiyorsa kutuyu çocuğa
vermeyin.

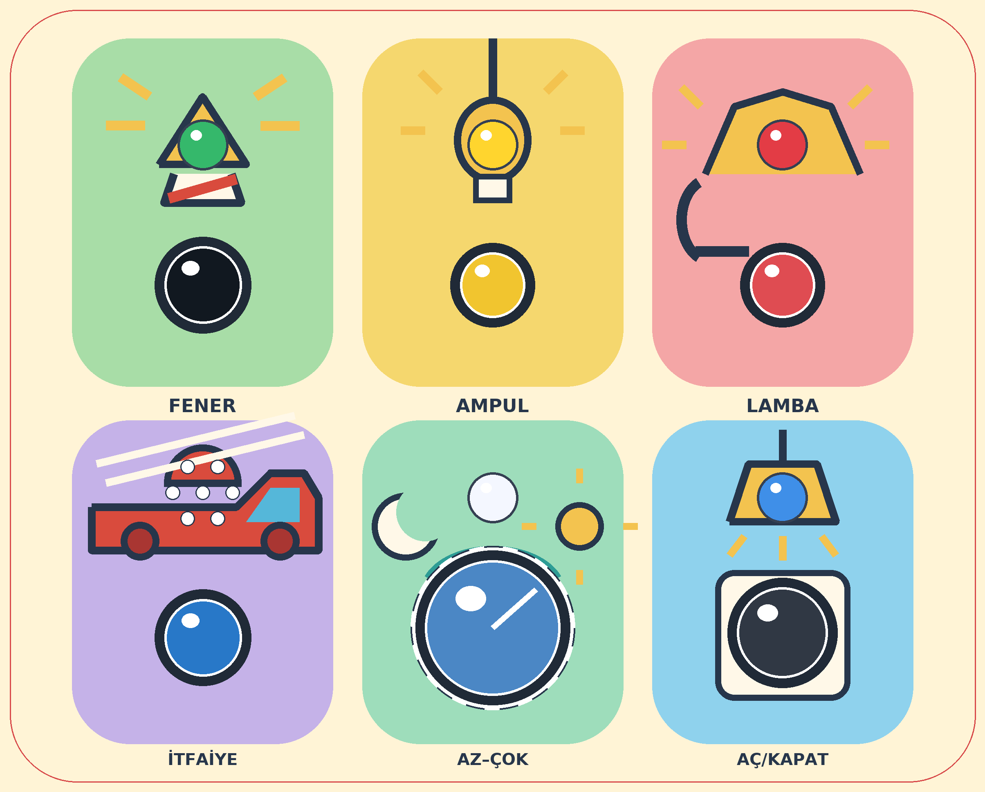
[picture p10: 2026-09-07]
artwork/tr/activity-box-assembled-preview.png

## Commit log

2026-09-04 feat: add educational activity box
    [BOM.csv, activity_box.scad, generated_dimensions.scad]
2026-09-04 feat: improve artwork and add fit coupon
    [activity_box.scad]
2026-09-04 feat: adapt box to purchased components
    [BOM.csv, activity_box.scad, generated_dimensions.scad]
2026-09-04 Reorder BOM.csv columns for consistency
    [BOM.csv]
2026-09-04 Fix formatting issues in BOM.csv
    [BOM.csv]
2026-09-04 feat: add component fit guide
    [activity_box.scad, generated_dimensions.scad]
2026-09-04 fix(docs): preserve public BOM schema
2026-09-05 fix(cad): apply measured component fits
    [BOM.csv, generated_dimensions.scad]
2026-09-05 fix(artwork): align label to exterior view
    CAD feature coordinates are viewed from inside the front panel. Swap outer columns so printed text stays readable on the existing body.
2026-09-06 fix(cad): clear dial from LED guard
    [activity_box.scad]
2026-09-07 feat: prepare bilingual open-source release
    [BOM.csv]
